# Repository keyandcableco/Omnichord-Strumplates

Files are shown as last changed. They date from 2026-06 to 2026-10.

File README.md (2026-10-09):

# Omnichord Strumplate Reproduction

flex PCB version 1.0

## 🎥 Demo Video

OM-84 Flex PCB Demo (https://youtube.com/shorts/RykH0IlZ8lg)

This project is an effort to reproduce the strumplate for the Suzuki Omnichord. It started with the OM-84 because that's what we had on hand, and now also covers the OM-27.

### Repo Structure

- `om84_strumplate/` — OM-84 work (flex PCB design, gerbers, references)
- `om27_strumplate/` — OM-27 work (in progress)
- `lib/keyandcable_branding.pretty/` — silkscreen footprints for the Key & Cable Co. logo lockup and the keyandcable.com QR code, printed on the ribbon tail of both flex PCBs

### Background

The Omnichord strumplate is a large capacitive touch sensor that lets you strum chords. Over time these plates commonly fail — the conductive surface wears out, traces crack, or sections stop responding.

Because the original strumplate is a glued multi-layer assembly, repairing or replacing it is extremely difficult. Original parts are long discontinued, and good donor units are hard to find.

### Project Goal

We're working on modern reproductions that can be used to restore broken units, starting with the OM-84 and OM-27.

A [brave technician](https://www.reddit.com/user/adamjsp/) is working to restore his own strumplate and generously shared high-quality scans. Those references are the main reason this project exists — we're now using them to design new, buildable versions.

### Current Status

Early stage. The goal is to create drop-in replacements that match the original feel and response as closely as possible.

**OM-84** (see `om84_strumplate/`)

UPDATE (JUNE 25, 2026)
Version 1.0 of the flex PCB works very well, may be a bit thin at 0.11mm, but certainly works. GERBERS updated, should come back from JLCPCB with no issue during review.

UPDATE (OCTOBER 8, 2026)
Both flex PCBs now carry the Key & Cable Co. logo, name and a QR code to keyandcable.com in white silkscreen on the ribbon tail, away from the contacts and the gold fingers. Each tail is also labelled with its model (OM-84 / OM-27) and version, now V1.1 on both (V1.0 was the first fab run; V1.1 adds the 1.25 mm finger pitch fix and the branding). The version is printed from the board's title-block revision (Board Setup > Title Block), so bump it there and re-plot. F_Silkscreen Gerbers and the production zips are updated.

**OM-27** (see `om27_strumplate/`)

Just getting started — early files only, nothing tested yet.

### 3D Printable Parts

There are now SCAD and STL files in progress for both models. The curves aren't quite right yet, so treat these as a starting point rather than final, print-ready parts.

### How to Help

- Getting the SCAD/STL curves dialed in for an accurate fit
- Measurements and dimensions of other models (e.g. OM-36)
- High-res photos of working and failed strumplates, all models

### To-Do
- ~~Tighten up gold teeth pitch, insertion errors sometimes?~~ Done: OM-84 and OM-27 gold fingers are now on a uniform 1.25 mm pitch, centred on the tail
- Perfect bottom curves of plates in SCAD
- Build guide, compare conductive layer materials
- Update OM-84 Kicad with full stiffener
- Clean up left-side alignment of stiffener layer in OM-27. Edges, too.

Feel free to open issues or pull requests if you want to contribute.

---

Any feedback or suggestions on the README itself is also welcome.

## License

Copyright © 2026 Greg Miller / The Key & Cable Company.

The strumplate designs (KiCad files, Gerbers, OpenSCAD models and artwork) are licensed under the [CERN Open Hardware Licence Version 2 – Strongly Reciprocal (CERN-OHL-S-2.0)](LICENSE). You can make, modify, sell and share hardware from them. If you share a modified design, or ship hardware made from one, you have to publish your design files under the same licence.

Source location: <https://github.com/keyandcableco/Omnichord-Strumplates>

Not covered, because they aren't ours to license:

- `om84_strumplate/3dp/om84_strumplate_v2_flat.*` and `om84_strumplate_v2_raised.*`, contributed by [AJ-EPS](https://github.com/AJ-EPS). They remain theirs.
- The photographs of the original Suzuki strumplate in `om84_strumplate/images/` (`Strum plate bottom + Trace plate top.jpg`, `Trace plate contact side.jpg`, `Trace plate top + Strum plate top.jpg`).

Omnichord is a trademark of Suzuki; it is used here only to say what these parts fit.

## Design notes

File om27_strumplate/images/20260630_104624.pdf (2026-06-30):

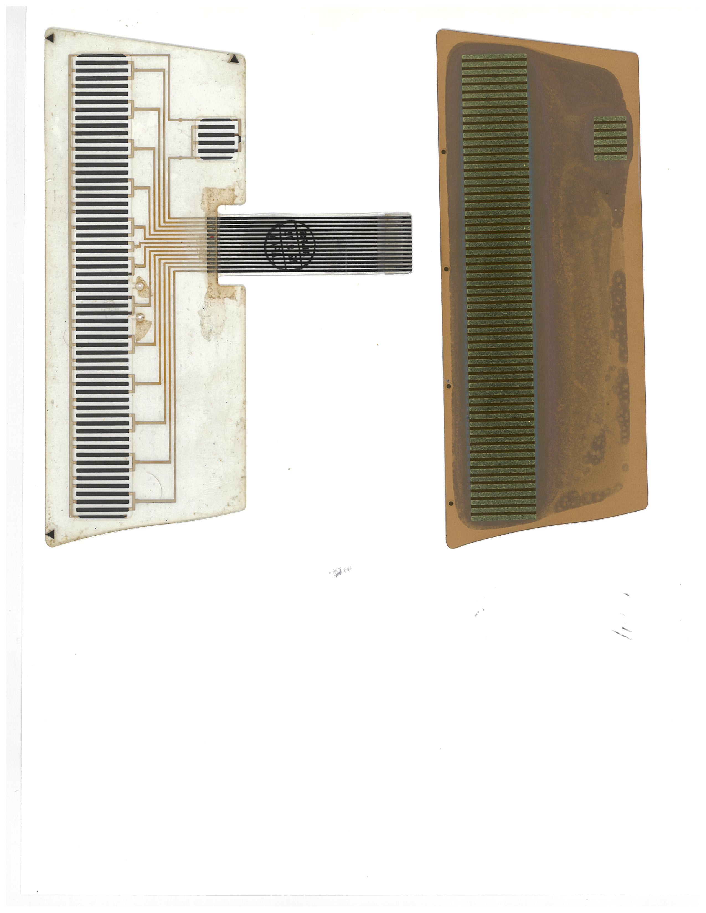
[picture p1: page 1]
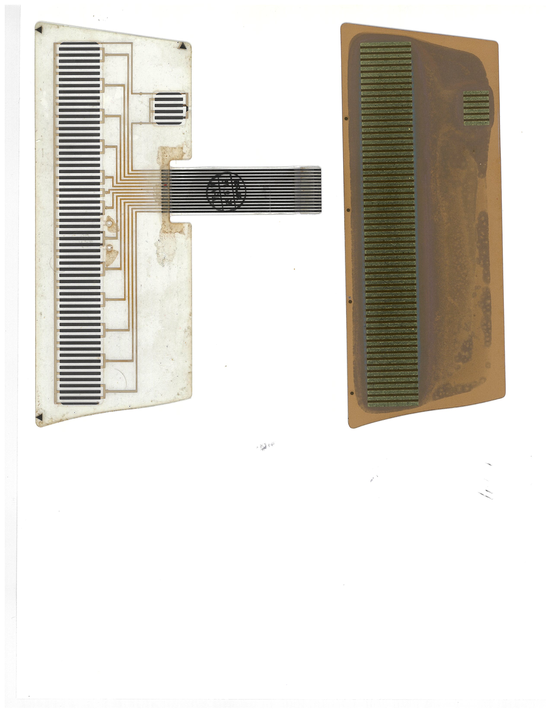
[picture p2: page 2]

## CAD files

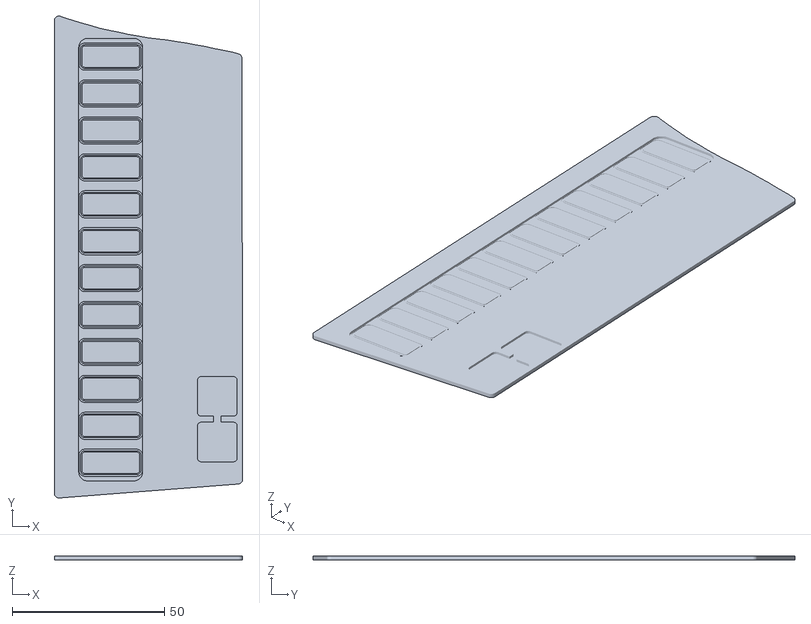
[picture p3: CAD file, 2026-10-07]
om27_strumplate/3dp/omnichord_om27_strumplate_w_moats.stl
61.8 x 158.2 x 1.20

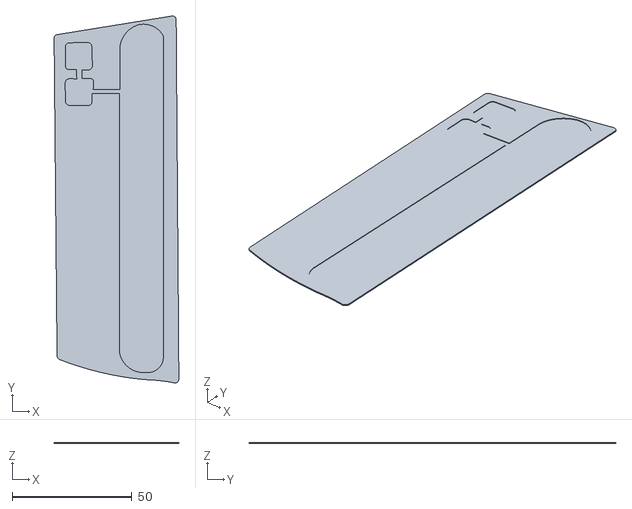
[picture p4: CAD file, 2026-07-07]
om84_strumplate/3dp/om84_strumplate_v2_raised.stl
52.1 x 153.2 x 0.4

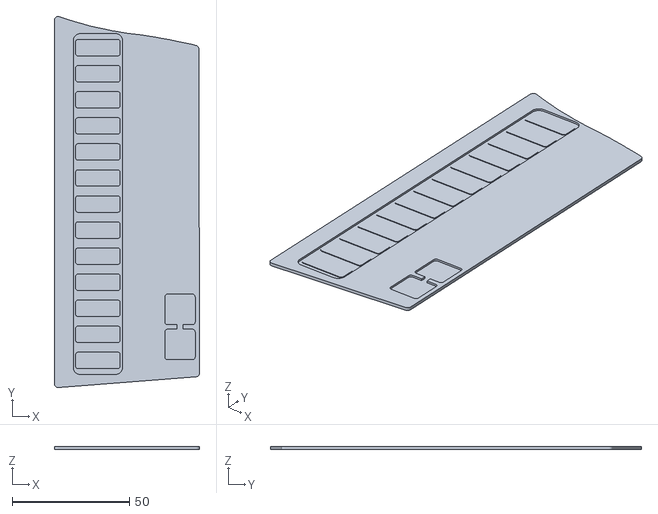
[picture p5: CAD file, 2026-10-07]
om27_strumplate/3dp/om27_strumplate.stl
61.8 x 158.2 x 1.20

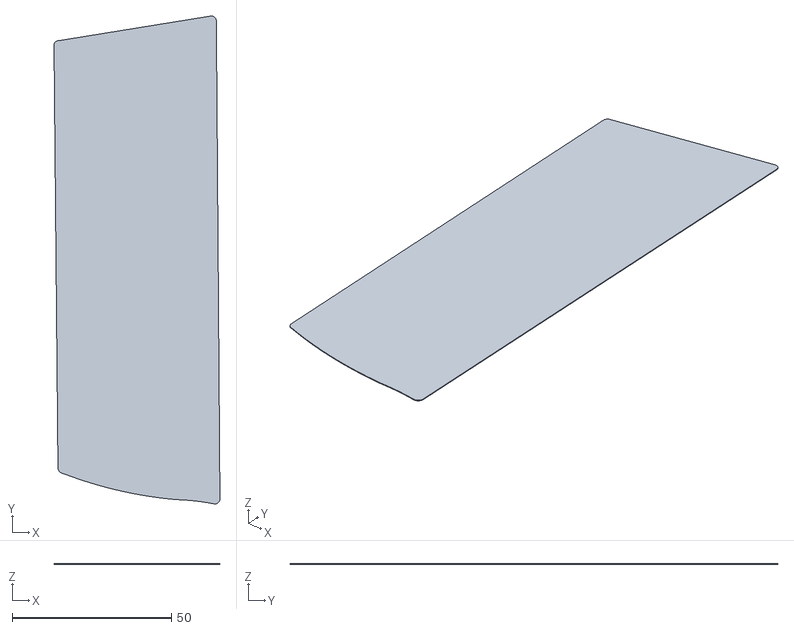
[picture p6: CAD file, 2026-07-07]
om84_strumplate/3dp/om84_strumplate_v2_flat.stl
52.1 x 153.2 x 0.2

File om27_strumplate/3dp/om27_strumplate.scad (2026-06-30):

// ============================================================
// Omnichord OM-27 Strumplate Top Plate
// ============================================================
// A cover plate that sits over the flex PCB strum strip.
// Two features create the gap needed between the flex PCB
// contacts and the conductive strumming surface:
//
//   1. MAIN VALLEY  -> a shallow recess: a slim rectangle with small
//      rounded corners at the short ends (NOT a fat pill/stadium),
//      running nearly the FULL length of the plate, independent of
//      where the pad cluster sits, cut to recess_depth.
//   2. PAD RECESS   -> a shallow pocket (same recess_depth) over the
//      small contact pad near the top, connected to a second
//      smaller pocket by a thin bridge slot (matches the two
//      cutouts + connecting tab seen in the reference CAD model).
//
// Both recesses are cut from the TOP face only, leaving a thin,
// paper-thin BOTTOM skin (bottom_skin_thickness) untouched -- that
// skin is the side the user's finger touches, and should be printed
// face-down on the bed as the first layer for max smoothness.
//
// Adjust the PARAMETERS block below to match your real
// measurements -- nothing else needs to change.
// ============================================================

/* [Overall plate -- asymmetric trapezoid with a curved top edge] */
// The two LONG edges (left & right) are PARALLEL to each other and are
// the sides the long valley recess runs alongside. The two SHORT edges
// (top & bottom) connect them and are NOT parallel to each other.
// The TOP short edge (opposite the pad cluster, which is mirrored to
// sit near the bottom in the 3D assembly below) is not straight.
edge_left_long   = 159;  // length of the long left edge, mm
edge_right_long  = 142;  // length of the long right edge, mm
edge_top_short   = 63;   // length of the short top edge, mm (straight-line/chord distance
                          // between TL and TR -- the curve deviates from this)
edge_bottom_short = 62;  // length of the short bottom edge, mm (straight)
corner_radius     = 1.5; // small rounding at all four corners (just enough to not be knife-sharp)

// --- Top edge curve: direct, editable point list ---
// Each entry is [t, dev]:
//   t   = position along the TL->TR chord, 0 = TL, 1 = TR
//   dev = perpendicular deviation from the straight chord, in mm
//         (POSITIVE = bulges OUT away from the plate body, NEGATIVE = dips IN)
// The curve is built by linearly interpolating between these points in
// order, so each point's effect is LOCAL -- nudge one [t, dev] pair and
// only the curve segments touching it move, unlike a Bezier where every
// control point affects the whole shape. Add more points for finer
// control anywhere you need it; t doesn't need to be evenly spaced.
// The first point should be [0, 0] (note: this curve doesn't return to
// 0 at t=1 -- it settles at -0.75, which is fine, just means TR sits
// slightly inset from the literal corner; t=1 is still anchored to TR
// in the construction below regardless of the dev value there).
// These points follow your last set (the ones that got close), just
// resampled to a finer 0.05 step using smooth monotone interpolation
// (PCHIP -- passes through your original points exactly, no
// overshoot/ringing introduced in between) so you have more individual
// handles to nudge.
TOP_CURVE_PTS = [
    [0.00, 0.0],
    [0.05, -0.531],
    [0.10, -0.9],
    [0.15, -1.2],
    [0.20, -1.45],
    [0.25, -1.75],
    [0.30, -1.8],
    [0.35, -1.8],
    [0.40, -1.9],
    [0.45, -1.8],
    [0.50, -1.75],
    [0.55, -1.521],
    [0.60, -1.25],
    [0.65, -1.15],
    [0.70, -1],
    [0.75, -1],
    [0.80, -0.9],
    [0.85, -1],
    [0.90, -1],
    [0.95, -1],
    [1.00, -1.25],
];
top_curve_resolution = 6; // segments to interpolate BETWEEN each pair of points
                          // (higher = smoother straight-line approximation of
                          // whatever shape you build with the points above;
                          // since interpolation is linear, this mostly just
                          // affects corner_radius rounding smoothness, not
                          // the underlying shape)

// --- Derived corner geometry (do not edit) ---
// Solve for the perpendicular distance `plate_w` between the two parallel
// long edges, and the vertical stagger `edge_offset` of the right edge
// relative to the left edge, such that the connecting short edges come
// out to edge_top_short / edge_bottom_short exactly (using the straight-
// line/chord length for the top edge, since the S-curve is added after).
// System (derived once and baked in as a closed-form solution):
//   bottom_short^2 = plate_w^2 + edge_offset^2
//   top_short^2    = plate_w^2 + (edge_left_long - (edge_offset + edge_right_long))^2
// Subtracting and solving for edge_offset:
_k = edge_left_long - edge_right_long;
edge_offset = ( (edge_bottom_short*edge_bottom_short) - (edge_top_short*edge_top_short) + (_k*_k) ) / (2*_k);
plate_w = sqrt(edge_bottom_short*edge_bottom_short - edge_offset*edge_offset);

// Corner coordinates (left edge along x=0, right edge along x=plate_w),
// then re-centered so x=0 sits on the long-axis centerline and y=0 sits
// at the vertical midpoint of the left edge, for convenient downstream use.
_BL = [0, 0];
_TL = [0, edge_left_long];
_BR = [plate_w, edge_offset];
_TR = [plate_w, edge_offset + edge_right_long];
_cx = plate_w/2;
_cy = edge_left_long/2;
BL = _BL - [_cx, _cy];
TL = _TL - [_cx, _cy];
BR = _BR - [_cx, _cy];
TR = _TR - [_cx, _cy];

// plate_length kept for backward compatibility with valley/pad placement
// below -- approximate overall span used for "distance from top" offsets.
plate_length = max(TL.y, TR.y) - min(BL.y, BR.y);

// The plate is built from two thicknesses stacked:
//   bottom_skin_thickness -> the touch surface (prints FIRST, face-down on the bed).
//                            Keep this paper-thin (1-2 perimeter layers, e.g. 0.2-0.4mm
//                            at a 0.2mm layer height) so finger contact can reach through
//                            wherever the recess above it is cut.
//   recess_depth           -> how deep the valley/pad recesses cut into the TOP face.
// plate_thickness is just their sum -- change the two thickness values, not this one.
bottom_skin_thickness = 0.45;   // <-- paper-thin touch surface, tune to your layer height
recess_depth          = 0.75;   // depth of the valley + pad recesses, cut from the top
plate_thickness        = bottom_skin_thickness + recess_depth;

/* [Main valley - shallow recess, sized to the OM-84 flex PCB contact row] */
// Measured from the OM-84 strumplate_traces.svg: 13 contacts, pitch
// 11.275mm center-to-center, each contact finger 13.698mm long (the
// across-strip dimension) x 4.421mm wide (the along-strip dimension).
contact_pitch       = 11.275; // mm, center-to-center spacing along the strip
contact_count       = 13;     // number of contacts in the row
valley_width      = 21;   // matches the OM-84 contact finger length (across-strip)
valley_length     = contact_pitch * (contact_count - 1) + 10; // total span of the row, ~139.7mm
valley_margin_top    = 8;  // gap kept between the top-left corner and the start of the valley
                             // (only used to help VERTICALLY CENTER the now fixed-length valley;
                             // see valley_2d() below)
valley_inset      = valley_width/2+8;    // how far in from the LEFT edge the recess sits, mm
valley_end_radius = 3;    // corner rounding radius at the two short ends (small radius,
                           // NOT half the width -- gives slim rounded-rect ends like the
                           // metallic strip in the reference photo, not a full pill cap)

/* [Pad recess cluster - sized to the OM-84 flex PCB pad contacts] */
// Measured from the same SVG: pad pitch 14.97mm center-to-center.
pad_contact_pitch = 14.97;  // mm, center-to-center spacing between the two pads
pad1_w = 13; pad1_h = 13;   // upper pad rectangle (rounded)
pad2_w = 13; pad2_h = 13;   // lower pad rectangle (rounded)
pad_corner_r       = 1.2;   // corner rounding for the pad rectangles
pad_gap            = pad_contact_pitch - pad1_h/2 - pad2_h/2; // vertical gap between pad1/pad2, derived from pitch
tab_width          = 2.5;   // width of the connecting bridge slot between pad1/pad2
min_wall_to_valley = 4;     // (unused now that spacing is set directly by distance below;
                             // kept only for reference/back-compat)
pad_to_valley_center_dist = 35; // distance between pad-cluster center and valley center, mm
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

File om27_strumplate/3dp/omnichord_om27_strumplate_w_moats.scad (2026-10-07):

// ============================================================
// Omnichord OM-27 Strumplate Top Plate
// ============================================================
// A cover plate that sits over the flex PCB strum strip.
// Two features create the gap needed between the flex PCB
// contacts and the conductive strumming surface:
//
//   1. MAIN VALLEY  -> a shallow recess: a slim rectangle with small
//      rounded corners at the short ends (NOT a fat pill/stadium),
//      running nearly the FULL length of the plate, independent of
//      where the pad cluster sits, cut to recess_depth.
//   2. PAD RECESS   -> a shallow pocket (same recess_depth) over the
//      small contact pad near the top, connected to a second
//      smaller pocket by a thin bridge slot (matches the two
//      cutouts + connecting tab seen in the reference CAD model).
//
// Both recesses are cut from the TOP face only, leaving a thin,
// paper-thin BOTTOM skin (bottom_skin_thickness) untouched -- that
// skin is the side the user's finger touches, and should be printed
// face-down on the bed as the first layer for max smoothness.
//
// The valley floor also carries a row of raised BUMPS, one per OM-27
// note (12 total), spaced at the note pitch -- these sit on the valley
// floor and rise toward (but stop short of) the top face.
//
// The BOTTOM touch face (z=0) also carries a small engraved MARKER per
// bump (number / dot / dash, selectable) so the player can see which
// "string" each bump corresponds to from the finger side.
//
// Adjust the PARAMETERS block below to match your real
// measurements -- nothing else needs to change.
// ============================================================

/* [Overall plate -- asymmetric trapezoid with a curved top edge] */
// The two LONG edges (left & right) are PARALLEL to each other and are
// the sides the long valley recess runs alongside. The two SHORT edges
// (top & bottom) connect them and are NOT parallel to each other.
// The TOP short edge (opposite the pad cluster, which is mirrored to
// sit near the bottom in the 3D assembly below) is not straight.
edge_left_long   = 159;  // length of the long left edge, mm
edge_right_long  = 142;  // length of the long right edge, mm
edge_top_short   = 63;   // length of the short top edge, mm (straight-line/chord distance
                          // between TL and TR -- the curve deviates from this)
edge_bottom_short = 62;  // length of the short bottom edge, mm (straight)
corner_radius     = 1.5; // small rounding at all four corners (just enough to not be knife-sharp)

// --- Top edge curve: direct, editable point list ---
// Each entry is [t, dev]:
//   t   = position along the TL->TR chord, 0 = TL, 1 = TR
//   dev = perpendicular deviation from the straight chord, in mm
//         (POSITIVE = bulges OUT away from the plate body, NEGATIVE = dips IN)
// The curve is built by linearly interpolating between these points in
// order, so each point's effect is LOCAL -- nudge one [t, dev] pair and
// only the curve segments touching it move, unlike a Bezier where every
// control point affects the whole shape. Add more points for finer
// control anywhere you need it; t doesn't need to be evenly spaced.
// The first point should be [0, 0] (note: this curve doesn't return to
// 0 at t=1 -- it settles at -0.75, which is fine, just means TR sits
// slightly inset from the literal corner; t=1 is still anchored to TR
// in the construction below regardless of the dev value there).
// These points follow your last set (the ones that got close), just
// resampled to a finer 0.05 step using smooth monotone interpolation
// (PCHIP -- passes through your original points exactly, no
// overshoot/ringing introduced in between) so you have more individual
// handles to nudge.
TOP_CURVE_PTS = [
    [0.00, 0.0],
    [0.05, -0.531],
    [0.10, -0.9],
    [0.15, -1.2],
    [0.20, -1.45],
    [0.25, -1.75],
    [0.30, -1.8],
    [0.35, -1.8],
    [0.40, -1.9],
    [0.45, -1.8],
    [0.50, -1.75],
    [0.55, -1.521],
    [0.60, -1.25],
    [0.65, -1.15],
    [0.70, -1],
    [0.75, -1],
    [0.80, -0.9],
    [0.85, -1],
    [0.90, -1],
    [0.95, -1],
    [1.00, -1.25],
];
top_curve_resolution = 6; // segments to interpolate BETWEEN each pair of points
                          // (higher = smoother straight-line approximation of
                          // whatever shape you build with the points above;
                          // since interpolation is linear, this mostly just
                          // affects corner_radius rounding smoothness, not
                          // the underlying shape)

// --- Derived corner geometry (do not edit) ---
// Solve for the perpendicular distance `plate_w` between the two parallel
// long edges, and the vertical stagger `edge_offset` of the right edge
// relative to the left edge, such that the connecting short edges come
// out to edge_top_short / edge_bottom_short exactly (using the straight-
// line/chord length for the top edge, since the S-curve is added after).
// System (derived once and baked in as a closed-form solution):
//   bottom_short^2 = plate_w^2 + edge_offset^2
//   top_short^2    = plate_w^2 + (edge_left_long - (edge_offset + edge_right_long))^2
// Subtracting and solving for edge_offset:
_k = edge_left_long - edge_right_long;
edge_offset = ( (edge_bottom_short*edge_bottom_short) - (edge_top_short*edge_top_short) + (_k*_k) ) / (2*_k);
plate_w = sqrt(edge_bottom_short*edge_bottom_short - edge_offset*edge_offset);

// Corner coordinates (left edge along x=0, right edge along x=plate_w),
// then re-centered so x=0 sits on the long-axis centerline and y=0 sits
// at the vertical midpoint of the left edge, for convenient downstream use.
_BL = [0, 0];
_TL = [0, edge_left_long];
_BR = [plate_w, edge_offset];
_TR = [plate_w, edge_offset + edge_right_long];
_cx = plate_w/2;
_cy = edge_left_long/2;
BL = _BL - [_cx, _cy];
TL = _TL - [_cx, _cy];
BR = _BR - [_cx, _cy];
TR = _TR - [_cx, _cy];

// plate_length kept for backward compatibility with valley/pad placement
// below -- approximate overall span used for "distance from top" offsets.
plate_length = max(TL.y, TR.y) - min(BL.y, BR.y);

// The plate is built from two thicknesses stacked:
//   bottom_skin_thickness -> the touch surface (prints FIRST, face-down on the bed).
//                            Keep this paper-thin (1-2 perimeter layers, e.g. 0.2-0.4mm
//                            at a 0.2mm layer height) so finger contact can reach through
//                            wherever the recess above it is cut.
//   recess_depth           -> how deep the valley/pad recesses cut into the TOP face.
// plate_thickness is just their sum -- change the two thickness values, not this one.
bottom_skin_thickness = 0.45;   // <-- paper-thin touch surface, tune to your layer height
recess_depth          = 0.75;   // depth of the valley + pad recesses, cut from the top
plate_thickness        = bottom_skin_thickness + recess_depth;

/* [Main valley - shallow recess, sized to the OM-84 flex PCB contact row] */
// Measured from the OM-84 strumplate_traces.svg: 13 contacts, pitch
// 11.275mm center-to-center, each contact finger 13.698mm long (the
// across-strip dimension) x 4.421mm wide (the along-strip dimension).
contact_pitch       = 11.275; // mm, center-to-center spacing along the strip
contact_count       = 13;     // number of contacts in the row
valley_width      = 21;   // matches the OM-84 contact finger length (across-strip)
valley_length     = contact_pitch * (contact_count - 1) + 10; // total span of the row, ~139.7mm
valley_margin_top    = 8;  // gap kept between the top-left corner and the start of the valley
                             // (only used to help VERTICALLY CENTER the now fixed-length valley;
                             // see valley_2d() below)
valley_inset      = valley_width/2+8;    // how far in from the LEFT edge the recess sits, mm
valley_end_radius = 3;    // corner rounding radius at the two short ends (small radius,
                           // NOT half the width -- gives slim rounded-rect ends like the
                           // metallic strip in the reference photo, not a full pill cap)
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

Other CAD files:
om84_strumplate/3dp/om84_strumplate_v2_flat.obj
om84_strumplate/3dp/om84_strumplate_v2_raised.obj

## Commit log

2026-06-10 Added Gerbers
    [BOM-om-84_strumplate.csv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]
2026-06-12 Fixed coverlay after JLCPCB feedback
    [om-84_strumplate-B_Cu.gbr, om-84_strumplate-B_Mask.gbr, om-84_strumplate-B_Paste.gbr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]
2026-06-26 Updated Gerbers, V1.0 confirmed working!
    [BOM-om-84_strumplate.csv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]
2026-06-30 Added KiCAD for OM-27, ordered V1.0
    [om27_strumplate-B_Cu.gbr, om27_strumplate-B_Mask.gbr, om27_strumplate-B_Paste.gbr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]
2026-07-01 Fixes after JLC feedback
    [om27_strumplate-B_Cu.gbr, om27_strumplate-B_Mask.gbr, om27_strumplate-B_Paste.gbr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]
2026-10-03 OM-84 flex: snap gold fingers to a uniform 1.25 mm pitch
    The 16 edge-connector fingers drifted up to 87 um off pitch (gaps
    ranged 1.20-1.33 mm). Move only the edge-end of each finger onto a
    1.25 mm grid centred on the tail, leaving the far ends and all trace
    connections untouched. Regenerated F_Cu gerber and production zip.
    Claude-Session: https://claude.ai/code/session_01Coe3Yi6vusjgo3QU814JYZ
    [om-84_strumplate.kicad_pcb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]
2026-10-04 OM-27 flex: snap gold fingers to a uniform 1.25 mm pitch
    The 14 fingers alternated between 1.234 and 1.279 mm pitch, T14 sat
    1.191 mm from T13, and the whole comb sat 0.07-0.21 mm toward one side
    of the tail. Add a bend at x=185 (just before the stiffener) and move
    the contact section of each finger onto a 1.25 mm grid centred on the
    tail; the long run behind it tilts slightly, nothing else moves.
    T14's tip corner now overlaps the rounded tail corner, so it is
    chamfered to keep 0.146 mm from the edge (it was 0.048 mm before).
    Regenerated F_Cu gerber and production zip.
    Claude-Session: https://claude.ai/code/session_01Coe3Yi6vusjgo3QU8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
    [om27_strumplate.kicad_pcb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]
2026-10-04 README: mark gold teeth pitch to-do as done
    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
2026-10-07 OM-27 strumplate: valley bumps, finger-side markers, and a moats variant
    The 3D-printed OM-27 plate gets a row of raised bumps on the valley floor, one per note, stopping
    short of the top face, and a small engraved marker per bump on the touch face (number, dot or dash)
    so the player can see which string is which. omnichord_om27_strumplate_w_moats is a variant with
    moats. README's to-do picks up the OM-84 stiffener and the OM-27 stiffener alignment.
    [om27_strumplate.stl, omnichord_om27_strumplate_w_moats.scad, omnichord_om27_strumplate_w_moats.stl]
2026-10-09 Add Key & Cable Co. branding to both flex tails
    White silkscreen on the ribbon tail of the OM-84 and OM-27 flex PCBs:
    the piano-key mark (10 mm, white key outlined, black key and plug
    filled, cable as a 0.25 mm stroke), "Key & Cable Co." and
    "keyandcable.com" in stroke text, and a QR code for
    https://keyandcable.com. The QR is version 3 at ECC level H; the ink
    prints the light modules and a 3-module quiet zone so the amber
    coverlay forms the dark modules. OM-84 uses 0.45 mm modules, the
    narrower OM-27 tail uses 0.42 mm. Everything sits over the traces,
    clear of the contacts, mask openings and gold-finger stiffeners.
    The artwork lives in lib/keyandcable_branding.pretty as reusable
    footprints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
    [om-84_strumplate.kicad_pcb, om27_strumplate.kicad_pcb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]
2026-10-09 Label both flex tails with model and version V1.1
    Each tail now carries its model in bold 2 mm silkscreen ("OM-84" /
    "OM-27") with the version under it. The version is printed from the
    board's title-block revision via ${REVISION}, so it is bumped in
    Board Setup > Title Block and also lands in the Gerber X2 headers.
    Both boards are set to 1.1: V1.0 was the first fab run, V1.1 adds the
    1.25 mm finger pitch fix and the Key & Cable branding.
    On the OM-84 the labels sit horizontally between the logo and the QR.
    The OM-27 tail has about 40 mm between the bend and the stiffener, so
    its labels are rotated 90 degrees into a column, and the logo and QR
    are re-spaced to keep at least 1.3 mm between el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
    [om-84_strumplate.kicad_pcb, om27_strumplate.kicad_pcb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]
